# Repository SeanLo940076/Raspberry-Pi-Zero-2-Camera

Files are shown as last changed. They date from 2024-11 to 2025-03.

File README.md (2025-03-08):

# Raspberry Pi Zero 2 Camera

[中文版本](README_zh.md)

This project provides all the files and information needed to build a **compact, portable Raspberry Pi Zero 2 camera**.

If you encounter any problems in usage, design, or programming, or if you have any suggestions for improvements, feel free to [open an Issue](../../issues) to discuss with us!

---

### Brief Features

- **Ultra-compact form factor**: Built around the Raspberry Pi Zero 2, making it easy to carry and deploy.
- **Auto-focus**: Utilizes the Raspberry Pi Camera Module 3 with AutoFocus support to capture sharper images.
- **Display and power integration**: Combines the Waveshare 1.3inch LCD HAT and Waveshare 1.3inch UPS HAT for a complete shooting experience.
- **Customizable, flexible expansion**: Raspberry Pi supports various camera modules and has a large open-source community, offering many interchangeable parts and 3D printing designs.

---

### Demo

**Finished Product / Camera Appearance**

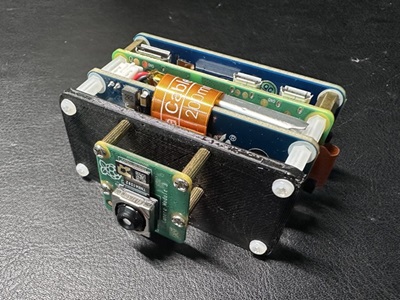
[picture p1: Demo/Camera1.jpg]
Demo Image

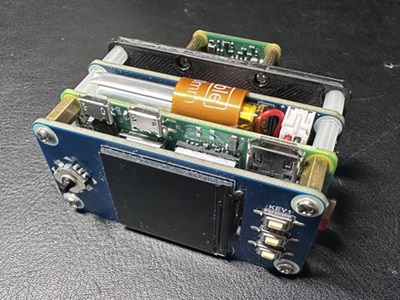
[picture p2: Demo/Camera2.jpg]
Demo Image


**Sample Photos - Click to view original images**

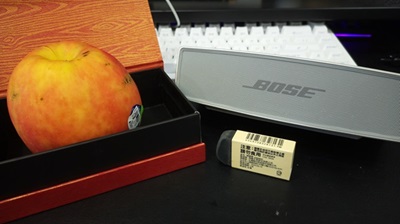
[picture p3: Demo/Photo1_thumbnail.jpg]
Demo Image 1

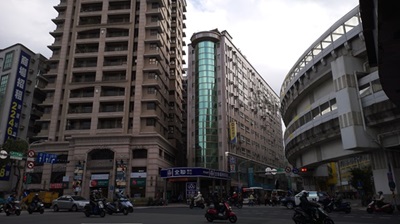
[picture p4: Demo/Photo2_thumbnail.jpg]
Demo Image 2


---

### Hardware Setup

1. **Hardware**:  
   - [Raspberry Pi Zero 2](https://www.raspberrypi.com/products/raspberry-pi-zero-2-w/)
   - [Raspberry Pi Camera Module 3](https://www.raspberrypi.com/products/camera-module-3/)
   - [Waveshare 1.3inch LCD HAT](https://www.waveshare.com/wiki/1.3inch_LCD_HAT)
   - [Waveshare 1.3inch UPS HAT](https://www.waveshare.com/wiki/UPS_HAT_(C))
   - [3D-printed camera adapter board](https://github.com/SeanLo940076/Raspberry-Pi-Zero-2-Camera/blob/main/3D%20Print/camera%20adapter%20board.stl) — a component to secure the camera. A simple design is included in this project for printing and fitting the Camera Module 3.
   - microSD

2. **Operating System**:  
   - Recommended **Raspberry Pi Lite OS**

---

### Assembly Steps

1. **Stack the LCD HAT**  
   - First, stack the **Waveshare 1.3inch LCD HAT** onto the **Pi Zero 2**, ensuring the 40-pin headers align correctly. Secure it with M2.5 screws in the four corners.

2. **Connect the flat cable**  
   - Use the included FFC cable to connect the camera interface on the **Pi Zero 2**.

3. **Stack the UPS HAT**  
   - Stack the **Waveshare 1.3inch UPS HAT** onto the **Pi Zero 2**, making sure the power pins align correctly. Secure it again with M2.5 screws in the four corners.
   - Note: It may be easier to thread the **FFC Cable** through the **UPS HAT** first before connecting it to the camera.

4. **Mount the Camera Module**  
   - Attach the **Camera Module 3** to the 3D-printed camera adapter board using M2 screws.

5. **Secure the camera adapter board**  
   - Stack the **camera adapter board** onto the back of the **UPS HAT** and secure it with M2.5 screws in the four corners.

6. **Power test**  
   - Connect a battery to the **UPS HAT** to charge.  
   - Confirm that the **Pi Zero 2** boots up properly and the LCD displays an image.

> **Tip**: Since this design is still under continuous improvement, if you find that the dimensions or hole placements are off, feel free to adjust the 3D model yourself.

---

### Installation / Usage Example

Below is an example based on **Raspberry Pi Lite OS**, demonstrating basic installation and shooting operations:

> You might see a message like “× This environment is externally managed” during installation. In that case, just proceed with:
   ```bash
   sudo apt install python3-requests
   ```

1. **Update the system and enable features**
   ```bash
   sudo apt update
   sudo apt upgrade -y
   sudo raspi-config
   ```
   - In `Interface Options`, enable **Camera**, **SPI**, **I2C**.

2. **Change the swap size**  
   In `/etc/dphys-swapfile`, find `CONF_SWAPSIZE` and change it to 512:
   ```bash
   sudo nano /etc/dphys-swapfile
   CONF_SWAPSIZE=512
   ```
   Then reboot.

3. **Install dependencies for the LCD HAT**
   ```bash
   wget https://github.com/joan2937/lg/archive/master.zip
   unzip master.zip
   cd lg-master
   sudo make install
   ```

   Then edit:
   ```bash
   sudo nano /boot/firmware/config.txt
   gpio=6,19,5,26,13,21,20,16=pu
   ```

4. **Install dependencies for the UPS HAT**
   ```bash
   sudo apt-get install p7zip
   wget https://files.waveshare.com/upload/4/40/UPS_HAT_C.7z
   7zr x UPS_HAT_C.7z -r -o./
   cd UPS_HAT_C
   python3 INA219.py
   ```

5. **Install OpenCV**
   ```bash
   sudo apt install python3-opencv-python
   ```

6. **Sync photos to a computer via Samba**
   ```bash
   sudo apt update
   sudo apt install samba
   sudo systemctl enable smbd
   sudo systemctl start smbd
   ```
   (Configuration for Samba can be organized later.)

7. **Run the camera software**
   ```bash
   python3 main.py
   ```

8. **Set up auto-start on boot**
   Edit the `rc.local` file:
   ```bash
   sudo nano /etc/rc.local
   ```

   > Switch to the specified user so that the script runs in the user's environment.
   > When running as root, the working directory and environment variables are different (e.g., the default path might be /root),
   > which can cause the script to fail in locating resources like the photo storage directory.
   
   Add the following line before `exit 0`, resulting in:
   > Replace “User” with your actual username
   ```bash

   su - User -c "/usr/bin/python3 /User/SeanPi-2w/Raspberry-Pi-Zero-2-Camera/Camera_v2/main.py &"
   exit 0
   ```

9. **Camera button guide**
   - KEY1 takes a photo
   - Left button opens the photo gallery
   - In the gallery, use left/right buttons to scroll through photos

---

### Features

**Current Functions**
1. **Auto-focus shooting**  
2. **Photo gallery**  
3. **Sync photos to computer**  
4. **Battery level estimation**  
5. **Program can auto-start on boot**

**Upcoming Updates**
- [ ] **Restart program button**
- [X] **Exit program button**
- [X] **Photo gallery error detection**
- [ ] **Auto-focus animation**
- [ ] **Improve battery level estimation**
- [X] **Adjust interaction mode**
- [ ] **Add joystick model and button model**
- [ ] **Optimize network connection**
- [ ] **Video recording**
- [X] **Add on-screen FPS calculation**

---

### License

This project is licensed under the MIT License. For more details, please refer to the [LICENSE](LICENSE) file.  
Thank you for reading, enjoy using this project, and we look forward to your feedback and contributions!

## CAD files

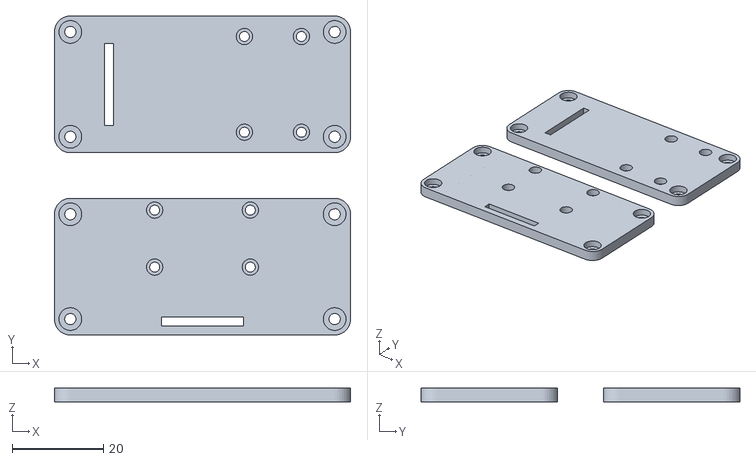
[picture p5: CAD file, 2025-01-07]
3D Print/camera adapter board.stl
65.0 x 70.0 x 3.00

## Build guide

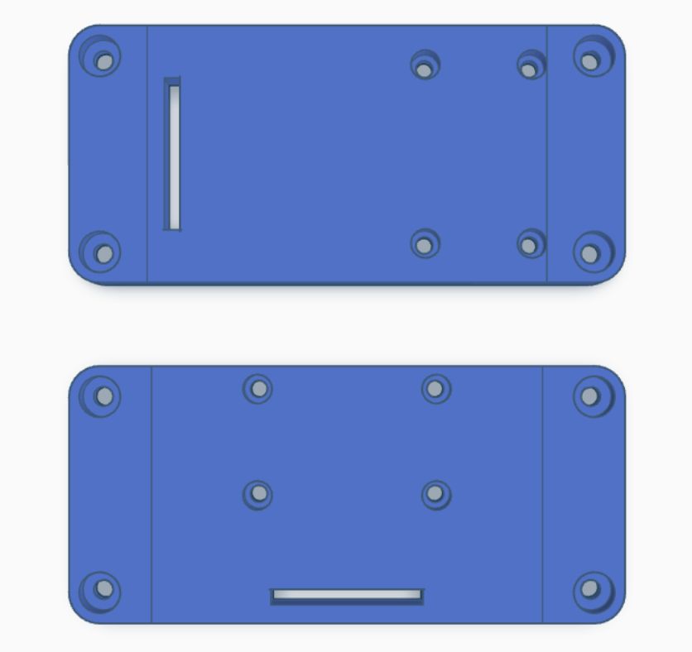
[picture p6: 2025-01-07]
3D Print/camera adapter board.png

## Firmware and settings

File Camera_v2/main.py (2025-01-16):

# main.py

import os
import logging
from camera_manager import CameraManager
from key_manager import KeyManager
from display_manager import DisplayManager
from state_machine import StateMachine
from battery_manager import BatteryManager

if __name__ == "__main__":
    logging.basicConfig(level=logging.INFO, format='%(asctime)s - %(levelname)s - %(message)s')

    # 初始化顯示器
    disp_mgr = DisplayManager()
    if disp_mgr.disp:
        # 初始化電池管理器
        battery_mgr = BatteryManager(update_interval=60)

        # 初始化相機管理器
        cam_mgr = CameraManager(disp_mgr)

        if cam_mgr.initialize_camera():
            key_mgr = KeyManager(disp_mgr.disp)

            # 使用當前使用者的家目錄作為基礎
            home_dir = os.path.expanduser("~")
            # 建立儲存影像的路徑
            save_dir = os.path.join(home_dir, "photo")
            os.makedirs(save_dir, exist_ok=True)

            # 初始化狀態機
            state_machine = StateMachine(disp_mgr, cam_mgr, key_mgr, battery_mgr, save_dir)

            # 主循環 - 使用狀態機來處理相機流程
            try:
                while True:
                    state_machine.run()  # 狀態機的運行邏輯

                    # 檢查按鍵，指定按鍵（例如 GPIO_KEY3_PIN）用於退出
                    if key_mgr.check_key_pressed(disp_mgr.disp.GPIO_KEY3_PIN):
                        logging.info("退出按鍵被按下，正在安全退出...")
                        break

            except KeyboardInterrupt:
                logging.info("程序被用戶中斷。")
            finally:
                # 清理資源
                cam_mgr.close_camera()
                disp_mgr.close_display()
                logging.info("程序已安全退出。")
        else:
            logging.error("相機初始化失敗。")
    else:
        logging.error("顯示初始化失敗。")

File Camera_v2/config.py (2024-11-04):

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

# config.py

import os
import sys
import time
import spidev
import logging
import numpy as np
from gpiozero import *


#GPIO define
KEY_UP_PIN     = 6
KEY_DOWN_PIN   = 19
KEY_LEFT_PIN   = 5
KEY_RIGHT_PIN  = 26
KEY_PRESS_PIN  = 13

KEY1_PIN       = 21
KEY2_PIN       = 20
KEY3_PIN       = 16

class RaspberryPi:
    def __init__(self,spi=spidev.SpiDev(0,0),spi_freq=40000000,rst = 27,dc = 25,bl = 24,bl_freq=1000,i2c=None,i2c_freq=100000):
        self.np=np
        self.INPUT = False
        self.OUTPUT = True

        self.SPEED  =spi_freq
        self.BL_freq=bl_freq

        self.GPIO_RST_PIN= self.gpio_mode(rst,self.OUTPUT)
        self.GPIO_DC_PIN = self.gpio_mode(dc,self.OUTPUT)
        self.GPIO_BL_PIN = self.gpio_pwm(bl)
        self.bl_DutyCycle(0)

        #init GPIO
        # for P4:
        # sudo vi /boot/config.txt
        # gpio=6,19,5,26,13,21,20,16=pu

        self.GPIO_KEY_UP_PIN     = self.gpio_mode(KEY_UP_PIN,self.INPUT,True,None)
        self.GPIO_KEY_DOWN_PIN   = self.gpio_mode(KEY_DOWN_PIN,self.INPUT,True,None)
        self.GPIO_KEY_LEFT_PIN   = self.gpio_mode(KEY_LEFT_PIN,self.INPUT,True,None)
        self.GPIO_KEY_RIGHT_PIN  = self.gpio_mode(KEY_RIGHT_PIN,self.INPUT,True,None)
        self.GPIO_KEY_PRESS_PIN  = self.gpio_mode(KEY_PRESS_PIN,self.INPUT,True,None)

        self.GPIO_KEY1_PIN       = self.gpio_mode(KEY1_PIN,self.INPUT,True,None)
        self.GPIO_KEY2_PIN       = self.gpio_mode(KEY2_PIN,self.INPUT,True,None)
        self.GPIO_KEY3_PIN       = self.gpio_mode(KEY3_PIN,self.INPUT,True,None)


        #Initialize SPI
        self.SPI = spi
        if self.SPI!=None :
            self.SPI.max_speed_hz = spi_freq
            self.SPI.mode = 0b00

    def gpio_mode(self,Pin,Mode,pull_up = None,active_state = True):
        if Mode:
            return DigitalOutputDevice(Pin,active_high = True,initial_value =False)
        else:
            return DigitalInputDevice(Pin,pull_up=pull_up,active_state=active_state)

    def digital_write(self, Pin, value):
        if value:
            Pin.on()
        else:
            Pin.off()

    def digital_read(self, Pin):
        return Pin.value

    def delay_ms(self, delaytime):
        time.sleep(delaytime / 1000.0)

    def gpio_pwm(self,Pin):
        return PWMOutputDevice(Pin,frequency = self.BL_freq)

    def spi_writebyte(self, data):
        if self.SPI!=None :
            self.SPI.writebytes(data)

    def bl_DutyCycle(self, duty):
        self.GPIO_BL_PIN.value = duty / 100

    def bl_Frequency(self,freq):# Hz
        self.GPIO_BL_PIN.frequency = freq

    def module_init(self):
        if self.SPI!=None :
            self.SPI.max_speed_hz = self.SPEED
            self.SPI.mode = 0b00
        return 0

    def module_exit(self):
        logging.debug("spi end")
        if self.SPI!=None :
            self.SPI.close()

        logging.debug("gpio cleanup...")
        self.digital_write(self.GPIO_RST_PIN, 1)
        self.digital_write(self.GPIO_DC_PIN, 0)
        self.GPIO_BL_PIN.close()
        time.sleep(0.001)



'''
if os.path.exists('/sys/bus/platform/drivers/gpiomem-bcm2835'):
    implementation = RaspberryPi()

for func in [x for x in dir(implementation) if not x.startswith('_')]:
    setattr(sys.modules[__name__], func, getattr(implementation, func))
'''

### END OF FILE ###

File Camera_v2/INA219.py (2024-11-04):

# INA219.py

import smbus
import time

# Config Register (R/W)
_REG_CONFIG                 = 0x00
# SHUNT VOLTAGE REGISTER (R)
_REG_SHUNTVOLTAGE           = 0x01

# BUS VOLTAGE REGISTER (R)
_REG_BUSVOLTAGE             = 0x02

# POWER REGISTER (R)
_REG_POWER                  = 0x03

# CURRENT REGISTER (R)
_REG_CURRENT                = 0x04

# CALIBRATION REGISTER (R/W)
_REG_CALIBRATION            = 0x05

class BusVoltageRange:
    """Constants for ``bus_voltage_range``"""
    RANGE_16V               = 0x00      # set bus voltage range to 16V
    RANGE_32V               = 0x01      # set bus voltage range to 32V (default)

class Gain:
    """Constants for ``gain``"""
    DIV_1_40MV              = 0x00      # shunt prog. gain set to  1, 40 mV range
    DIV_2_80MV              = 0x01      # shunt prog. gain set to /2, 80 mV range
    DIV_4_160MV             = 0x02      # shunt prog. gain set to /4, 160 mV range
    DIV_8_320MV             = 0x03      # shunt prog. gain set to /8, 320 mV range

class ADCResolution:
    """Constants for ``bus_adc_resolution`` or ``shunt_adc_resolution``"""
    ADCRES_9BIT_1S          = 0x00      #  9bit,   1 sample,     84us
    ADCRES_10BIT_1S         = 0x01      # 10bit,   1 sample,    148us
    ADCRES_11BIT_1S         = 0x02      # 11 bit,  1 sample,    276us
    ADCRES_12BIT_1S         = 0x03      # 12 bit,  1 sample,    532us
    ADCRES_12BIT_2S         = 0x09      # 12 bit,  2 samples,  1.06ms
    ADCRES_12BIT_4S         = 0x0A      # 12 bit,  4 samples,  2.13ms
    ADCRES_12BIT_8S         = 0x0B      # 12bit,   8 samples,  4.26ms
    ADCRES_12BIT_16S        = 0x0C      # 12bit,  16 samples,  8.51ms
    ADCRES_12BIT_32S        = 0x0D      # 12bit,  32 samples, 17.02ms
    ADCRES_12BIT_64S        = 0x0E      # 12bit,  64 samples, 34.05ms
    ADCRES_12BIT_128S       = 0x0F      # 12bit, 128 samples, 68.10ms

class Mode:
    """Constants for ``mode``"""
    POWERDOW                = 0x00      # power down
    SVOLT_TRIGGERED         = 0x01      # shunt voltage triggered
    BVOLT_TRIGGERED         = 0x02      # bus voltage triggered
    SANDBVOLT_TRIGGERED     = 0x03      # shunt and bus voltage triggered
    ADCOFF                  = 0x04      # ADC off
    SVOLT_CONTINUOUS        = 0x05      # shunt voltage continuous
    BVOLT_CONTINUOUS        = 0x06      # bus voltage continuous
    SANDBVOLT_CONTINUOUS    = 0x07      # shunt and bus voltage continuous


class INA219:
    def __init__(self, i2c_bus=1, addr=0x40):
        self.bus = smbus.SMBus(i2c_bus);
        self.addr = addr

        # Set chip to known config values to start
        self._cal_value = 0
        self._current_lsb = 0
        self._power_lsb = 0
        self.set_calibration_16V_5A()

    def read(self,address):
        data = self.bus.read_i2c_block_data(self.addr, address, 2)
        return ((data[0] * 256 ) + data[1])

    def write(self,address,data):
        temp = [0,0]
        temp[1] = data & 0xFF
        temp[0] =(data & 0xFF00) >> 8
        self.bus.write_i2c_block_data(self.addr,address,temp)

    def set_calibration_16V_5A(self):
        """Configures to INA219 to be able to measure up to 16V and 5A of current. Counter
           overflow occurs at 16A.
           ..note :: These calculations assume a 0.01 shunt ohm resistor is present
        """
        # By default we use a pretty huge range for the input voltage,
        # which probably isn't the most appropriate choice for system
        # that don't use a lot of power.  But all of the calculations
        # are shown below if you want to change the settings.  You will
        # also need to change any relevant register settings, such as
        # setting the VBUS_MAX to 16V instead of 32V, etc.

        # VBUS_MAX = 16V             (Assumes 16V, can also be set to 32V)
        # VSHUNT_MAX = 0.08          (Assumes Gain 2, 80mV, can also be 0.32, 0.16, 0.04)
        # RSHUNT = 0.01               (Resistor value in ohms)

        # 1. Determine max possible current
        # MaxPossible_I = VSHUNT_MAX / RSHUNT
        # MaxPossible_I = 8.0A

        # 2. Determine max expected current
        # MaxExpected_I = 5.0A

        # 3. Calculate possible range of LSBs (Min = 15-bit, Max = 12-bit)
        # MinimumLSB = MaxExpected_I/32767
        # MinimumLSB = 0.0001529              (61uA per bit)
        # MaximumLSB = MaxExpected_I/4096
        # MaximumLSB = 0,0012207              (488uA per bit)

        # 4. Choose an LSB between the min and max values
        #    (Preferrably a roundish number close to MinLSB)
        # CurrentLSB = 0.00016 (uA per bit)
        self._current_lsb = 0.1524  # Current LSB = 100uA per bit

        # 5. Compute the calibration register
        # Cal = trunc (0.04096 / (Current_LSB * RSHUNT))
        # Cal = 13434 (0x347a)

        self._cal_value = 26868

        # 6. Calculate the power LSB
        # PowerLSB = 20 * CurrentLSB
        # PowerLSB = 0.002 (2mW per bit)
        self._power_lsb = 0.003048  # Power LSB = 2mW per bit

        # 7. Compute the maximum current and shunt voltage values before overflow
        #
        # Max_Current = Current_LSB * 32767
        # Max_Current = 3.2767A before overflow
        #
        # If Max_Current > Max_Possible_I then
        #    Max_Current_Before_Overflow = MaxPossible_I
        # Else
        #    Max_Current_Before_Overflow = Max_Current
        # End If
        #
        # Max_ShuntVoltage = Max_Current_Before_Overflow * RSHUNT
        # Max_ShuntVoltage = 0.32V
        #
        # If Max_ShuntVoltage >= VSHUNT_MAX
        #    Max_ShuntVoltage_Before_Overflow = VSHUNT_MAX
        # Else
        #    Max_ShuntVoltage_Before_Overflow = Max_ShuntVoltage
        # End If

        # 8. Compute the Maximum Power
        # MaximumPower = Max_Current_Before_Overflow * VBUS_MAX
        # MaximumPower = 3.2 * 32V
        # MaximumPower = 102.4W

        # Set Calibration register to 'Cal' calculated above
        self.write(_REG_CALIBRATION,self._cal_value)

        # Set Config register to take into account the settings above
        self.bus_voltage_range = BusVoltageRange.RANGE_16V
        self.gain = Gain.DIV_2_80MV
        self.bus_adc_resolution = ADCResolution.ADCRES_12BIT_32S
        self.shunt_adc_resolution = ADCResolution.ADCRES_12BIT_32S
        self.mode = Mode.SANDBVOLT_CONTINUOUS
        self.config = self.bus_voltage_range << 13 | \
                      self.gain << 11 | \
                      self.bus_adc_resolution << 7 | \
                      self.shunt_adc_resolution << 3 | \
                      self.mode
        self.write(_REG_CONFIG,self.config)

    def getShuntVoltage_mV(self):
        self.write(_REG_CALIBRATION,self._cal_value)
        value = self.read(_REG_SHUNTVOLTAGE)
        if value > 32767:
            value -= 65535
        return value * 0.01
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

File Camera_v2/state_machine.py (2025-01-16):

# state_machine.py

import logging
import os
import cv2
from enum import Enum
import time
from threading import Thread
from thumbnail_manager import ThumbnailManager
from libcamera import controls
from picamera2 import Picamera2, Preview

class State(Enum):
    PREVIEW = 1
    VIEW_IMAGE = 2
    CAPTURE = 3

class StateMachine:
    def __init__(self, display_mgr, cam_mgr, key_mgr, battery_mgr, save_dir):
        self.display_mgr = display_mgr
        self.camera_mgr = cam_mgr
        self.key_mgr = key_mgr
        self.battery_mgr = battery_mgr
        self.state = State.PREVIEW
        self.thumbnail_mgr = ThumbnailManager(save_dir, os.path.join(save_dir, "thumbnails"))
        self.thumbnail_mgr.preload_thumbnails()
        self.image_index = None

    def handle_preview_state(self):
        raw_image = self.camera_mgr.picam2.capture_array()

        if raw_image is None or raw_image.size == 0:
            logging.error("預覽模式下捕捉到無效影像")
            return

        battery_percentage = self.battery_mgr.get_battery_percentage()

        current_time = time.strftime("%H:%M:%S")
        current_date = time.strftime("%Y/%m/%d")

        self.display_mgr.display_image_with_state(raw_image, "Capture", date_text=current_date, time_text=current_time, battery_percentage=battery_percentage)

        if self.key_mgr.check_key_pressed(self.display_mgr.disp.GPIO_KEY1_PIN):
            self.state = State.CAPTURE

        elif self.key_mgr.check_key_pressed(self.display_mgr.disp.GPIO_KEY_LEFT_PIN):
            self.state = State.VIEW_IMAGE
            self.image_index = len(self.thumbnail_mgr.image_paths) - 1

    def handle_capture_state(self):
        logging.info("開始拍照...")

        high_res_image = self.camera_mgr.capture_high_res_image_to_memory()

        if high_res_image is not None:
            def save_image_and_thumbnail(image):
                current_time = time.strftime("%Y%m%d_%H%M%S")
                image_path = os.path.join(self.thumbnail_mgr.save_dir, f"{current_time}.jpg")
                if cv2.imwrite(image_path, image):
                    self.thumbnail_mgr.update_image_list()
                    logging.info(f"圖片已保存: {image_path}")
                else:
                    logging.error(f"保存圖片失敗: {image_path}")

            Thread(target=save_image_and_thumbnail, args=(high_res_image,)).start()
            logging.info("後台保存中，返回到預覽模式...")
        else:
            logging.error("未捕捉到有效的圖片")

        self.state = State.PREVIEW

    def handle_view_image_state(self):
        if self.image_index is None:
            self.image_index = len(self.thumbnail_mgr.image_paths) - 1

        if self.image_index is not None:
            image_path = self.thumbnail_mgr.image_paths[self.image_index]
            image = self.thumbnail_mgr.load_or_generate_thumbnail(image_path)

            if image is None:
                logging.error(f"無法加載圖片: {image_path}")
                return

            filename = os.path.basename(image_path).split(".")[0]
            date_part = filename[:8]
            time_part = filename[9:]

            # 保證日期格式統一為 YYYY/MM/DD，並包含秒數
            image_date = f"{date_part[:4]}/{date_part[4:6]:0>2}/{date_part[6:8]:0>2}"
            image_time = f"{time_part[:2]}:{time_part[2:4]}:{time_part[4:6]}"

            total_images = len(self.thumbnail_mgr.image_paths)
            current_image_info = f"{self.image_index + 1}/{total_images}"

            battery_percentage = self.battery_mgr.get_battery_percentage()

            self.display_mgr.display_image_with_state(image, current_image_info, date_text=image_date, time_text=image_time, battery_percentage=battery_percentage)

            if self.key_mgr.check_key_pressed(self.display_mgr.disp.GPIO_KEY_LEFT_PIN):
                if self.image_index > 0:
                    self.image_index -= 1
            elif self.key_mgr.check_key_pressed(self.display_mgr.disp.GPIO_KEY_RIGHT_PIN):
                if self.image_index < len(self.thumbnail_mgr.image_paths) - 1:
                    self.image_index += 1

            if self.key_mgr.check_key_pressed(self.display_mgr.disp.GPIO_KEY_UP_PIN):
                self.state = State.PREVIEW

    def run(self):
        if self.state == State.PREVIEW:
            self.handle_preview_state()
        elif self.state == State.VIEW_IMAGE:
            self.handle_view_image_state()
        elif self.state == State.CAPTURE:
            self.handle_capture_state()

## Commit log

2024-10-26 Initial commit for Raspberry Pi camera display project
2024-11-04 camera version 2
2024-11-04 Add battery detection, add focus function, add point pool display function, change thumbnail method
2024-11-04 Adjust development version name, Fix software errors in version 2
    [INA219.py, ST7789.py, camera_manager.py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]
2025-01-07 Add 3D print and update readme
    [camera adapter board.stl]
2025-01-07 Remove camera_0830 from main branch
2025-01-07 Add 3D print preview & update readme
2025-01-07 Refactor: store photos in the current user's home directory instead of a hardcoded path
2025-01-08 Enable camera program to auto-start on boot
2025-01-16 Added "Close program function key", "Photo browsing problem detection", "Adjust function interaction mode"
    [battery_manager.py, camera_manager.py, display_manager.py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]
